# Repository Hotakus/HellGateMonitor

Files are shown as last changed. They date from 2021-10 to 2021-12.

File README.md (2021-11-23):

# Hell Gate Monitor（HGM）
### 微型的MC风格多功能无线监控副屏（开发中）  

### [项目当前待实现目标](https://github.com/Hotakus/HellGateMonitor/issues/3)

---








<div align=center>
    
</div>

---

## 一、基本信息：

> 主控: &emsp; &emsp; ESP32-PICO-D4 (240Mhz，4MB Flash，512KB RAM )  
> PSRAM: &emsp;ESP-PSRAM64 (8MB SPI RAM)   
> 电源管理:&emsp;IP5109  
> IMU: &emsp; &emsp; &nbsp;MPU6050  
> USB串口:&emsp;CP2104    
> LDO芯片:&emsp;XC6210B332 700mA   
> 屏幕: &emsp; &emsp; 1.14英寸 135x240分辨率IPS  
> 锂电池:&emsp; &nbsp; 700mAh 3.7V  
>   
从硬件上看，ESP32系列只要支持**PSRAM**，则代码通用。 

## 二、GUI
[**LittleVGL**](https://github.com/lvgl/lvgl)

---
## 三、基本功能：
>通过蓝牙安卓APP进行Hell Gate Monitor 的 __实时控制与WiFi配置等__  
>通过WiFi对局域网PC进行实时的 __硬件信息监控__ 显示（通过我的另外一个项目 
> [HGMC](https://github.com/Hotakus/HGMC) 后续考虑Linux版本
> ）  
>通过WiFi进行PC的 __屏幕投屏__  
>通过WiFi进行实时的 __天气与时钟显示__  
>通过WiFi进行实时的 __B站基本信息显示__（通过我的蓝牙APP进行B站配置）  

__蓝牙默认名：__ HellGateMonitorBT  
Bluetooth 和 Wi-Fi TCP 与上位机通信的数据包格式为本人规定的固定格式的json数据包组成，采用命令代码方式进行数据交互
，可通过命令和固件定制，添加更多功能。  

[HGM 的蓝牙JSON数据包格式](./Source/HgmApp/HgmBT/README.md)  
[HGM 的WiFi TCP JSON数据包格式](./Source/HgmApp/HgmWiFi/HgmTCP/README.md)

---

## 四、项目克隆：
项目使用了 __子模块__，clone 时要加 __--recurse-submodules__  
需要为你的Github账号配置 SSH key（方法请百度）
```shell
git clone --recurse-submodules git@github.com:Hotakus/HellGateMonitor.git
```

---

## 五、项目基本结构（TDDO）：

---

## 六、开始项目编译（TDDO）
__最后：__  
tb

如果编译烧写正常，那么串口会出现以下信息(115200)：  
HGM  
则项目构建完成。

---

## 七、不会编译，想直接使用👇
如果你觉得编译太麻烦，或者不会编译，
那么可以直接使用我编译好的固件：[固件下载 TODO]()  
然后按照以下流程配置并烧写固件：
- 首先，进入目录：Tool/hgm_spiffs/base_dir/, 按照里面的文件模板进行配置，如WiFi的SSID和密码、B站配置等
- 第二，双击运行目录下的bat脚本：Tool/hgm_spiffs/hgm_spiffs_gen.bat，它会自动生成适用于HGM的spiffs固件
- 第三，USB连接HellGateMonitor，文件和烧写地址要填对，选择正确的串口，
使用Tool下的flash_download_tool工具按如下方式烧写👇。
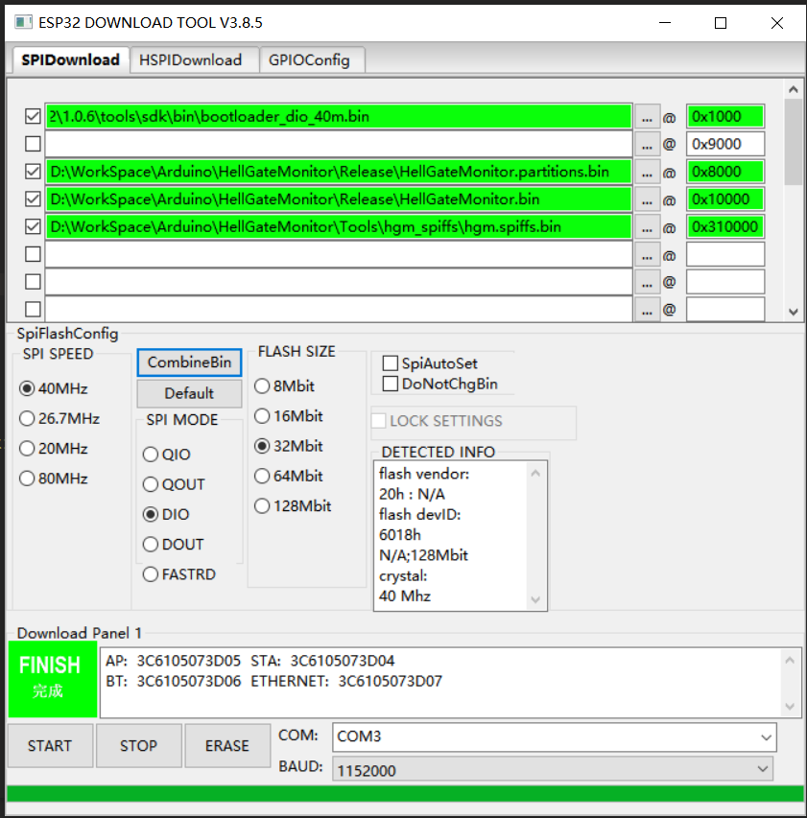
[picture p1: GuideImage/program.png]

- 最后，按下HellGateMonitor的电源键复位，然后就可以开始使用咯✌

---

## 八、HGM的初次上电启动流程（重要）：
HGM的上电时需要对各个功能组件进行检查：  
关于配置文件：如果你使用Tool/hgm_spiffs/hgm_spiffs_gen.bat工具生成的话，运行就不会failed

- **Bluetooth**（用于HGM的控制和配置等）
- **Config**（初次启动没有任何配置文件，首次运行会failed，用 [HGMA](https://github.com/Hotakus/HGMA) 配置）
- **WiFi**（HGM的各个功能基本依赖于此，非常重要，必须进行配置）
- **Time**（基本时钟矫正，开启后每24小时矫正一次）
- **Weather**（天气组件，首次运行会failed，用 [HGMA](https://github.com/Hotakus/HGMA) 配置，每30分钟获取一次）
- **BiliBili**（B站组件，首次运行会failed，用 [HGMA](https://github.com/Hotakus/HGMA) 配置，每10分钟获取一次B站信息）

---

## 九、部分功能上手配置说明：
### 1、如何配置并使用局域网PC硬件监控功能（HGM核心功能）
需要使用我的PC上位机配套项目： [HGMC](https://github.com/Hotakus/HGMC)    
要想使用PC硬件监控功能，那么必须要配合上位机实现，
参考我的另外一个开源项目 [HGMC](https://github.com/Hotakus/HGMC) （PC端硬件监控和HGM投屏管理中心软件），
使用 [HGMC](https://github.com/Hotakus/HGMC) 对PC进行监控或投屏，监控数据会实时发送给HGM，投屏功能可选择开启。

### 2、如何配置并使用天气功能
天气功能所使用的API为“ [和风天气](https://id.qweather.com) ”提供的API
，要想使用天气功能，
那么你必须去“ [和风天气控制台](https://id.qweather.com/#/login?redirect=https%3A%2F%2Fconsole.qweather.com) ”创建应用，
然后获得APP key（免费），这个key是天气功能开启的关键，HGM默认不开启天气功能，要想使用天气功能，
需要获得key后，用 [HGMA](https://github.com/Hotakus/HGMA) （HGM的安卓配置APP）配置HGM，即可使用。

### 3、如何使用安卓APP配置和控制HGM
需要使用我的安卓APP配套项目：[HGMA](https://github.com/Hotakus/HGMA)   

**HGMA**可以干什么？
* 配置WiFi（配置后自动在SPIFFS里生成 **/wifi.conf** 文件，SSID 和 password）
* 配置天气API（配置后自动在SPIFFS里生成 **/weather.conf** 文件，包括APP key和天气获取的默认地区等信息）
* 配置B站信息（配置后自动在SPIFFS里生成 **/bilibili.conf** 文件，即你的B站UID、头像地址等信息）
* 配置 ”硬件监控UI“ 的布局
* 提供简单的蓝牙调试功能，不是HGM也能用

配置完成后，以后每次启动HGM都会优先读取SPIFFS的各个配置文件，以后不用再打开HGMA，除非需要二次配置。

---

## FA♂Q
#### Q: 成本是多少？
A：TODO

---

**开头** 的这些Badge可以点击哦👇👇👇    
prompt

---

<br>
<br>
<br>
<br>
<br>
<br>
<br>
<br>
<br>
<br>
<br>
<br>
<br>

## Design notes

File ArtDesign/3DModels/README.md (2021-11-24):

# HGM 外壳制造
## 一、按照下面流程制造👇
### 3D打印：
精度越高越好，最好给厂家定制  
打印以下3个文件：
* HGM顶盖
* HGM壳
* HGM屏垫片

打印材料：
- PA12-HP工业尼龙（固有色：灰黑色，自己上色）
- PAC-HP尼龙（彩色，贵，彩色文件未上传）

### 亚克力透明底壳（标注2mm厚）：
发给亚克力定制厂家：[HGM透明底壳草图文件.dwg ]()

### 亚克力屏盖（标注0.3mm厚，25mm宽，38mm长）
因为是只有长和宽的需求，所以没有文件，直接和厂家说要这个尺寸

## 二、装配
装配需要另购4个M2自攻螺丝  
TODO

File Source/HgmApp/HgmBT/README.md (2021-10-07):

# HgmBT

HGM的蓝牙数据包格式(JSON)

---

## 下位机数据包格式

|------|数据头标识|数据类型 |数据块 |
|:----:|:---:|:---:|:---:|
| **Key**|Header |DataType  |Data |
| **Value**|HgmBT  |dt (见下文)|data(见下文)|

可以自己添加命令实现更多功能(详见 [BT代码](./HgmBT.h) )



## 数据包示例：
**获取命令长度M（被动）** （DataType == 0）
```json
{
  "Header": "Hgm",
  "DataType": "0",
  "Data": ""
}
```
返回长度M

**普通数据接收（被动）** （DataType == 3）
```json
{
  "Header": "Hgm",
  "DataType": "3",
  "Data": "Hello world! HellGateMonitor!!!"
}
```

普通数据模式下，HGM接收后在串口终端输出相应Data信息

**WiFi配置和开启（被动）** （DataType == 4）

```json
{
  "Header": "Hgm",
  "DataType": "4",
  "Data": {
    "ssid": "xxx",
    "password": "xxx"
  }
}
```

**WiFi关闭（被动）** （DataType == 5）

```json
{
  "Header": "Hgm",
  "DataType": "5",
  "Data": "Any content"
}
```

**天气等信息配置（被动）** （DataType == 6）  
API详见“ [和风天气API](https://dev.qweather.com/docs/api/) ”，若只是使用则不需要了解

```json
{
  "Header": "Hgm",
  "DataType": "6",
  "Data": {
    "lat": "39.92149",
    "lon": "116.48641",
    "key": "xxxxxxxxxxxxxxx"
  }
}
```

**B站配置（被动）** （DataType == 7）

```json
{
  "Header": "Hgm",
  "DataType": "7",
  "Data": {
    "uid": "xxx"
  }
}
```
**配置硬件监控UI（被动）** （DataType == 8）
```json
{
  "Header": "Hgm",
  "DataType": "8",
  "Data": {
    "isDefault" : "1",
    "leftTop" : "CPU",
    "leftBottom" : "GPU",
    "rightTop" : "Memory",
    "rightBottom" : "HardDisk"
  }
}
```
**default** 为 1 代表使用默认配置，为 0 代表使用新配置，并覆写配置文件  
**Data** 候选有：CPU、GPU、Memory、HardDisk、Network

<br>

#### 中间可以添加更多命令........

<br>

**空数据包** （DataType == M）

```json
{
  "Header": "Hgm",
  "DataType": "M",
  "Data": ""
}
```

---

## 上位机接收格式

同 “下位机接收格式”

---

下位机接收成功返回给对方一个JSON数据包：  
OK（DataType == 1）

```json
{
  "Header": "Hgm",
  "DataType": "1",
  "Data": "ok"
}
```

ERROR（DataType == 2）

```json
{
  "Header": "Hgm",
  "DataType": "2",
  "Data": "error"
}
```

---

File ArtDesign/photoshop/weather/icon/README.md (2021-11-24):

#### 天气图标改自：[和风天气天气图标](https://dev.qweather.com/docs/resource/icons/)

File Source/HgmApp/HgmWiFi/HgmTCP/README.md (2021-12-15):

# HgmTCP

HGM的TCP数据包格式(JSON)

---  

蓝牙默认开启，在HGMC与HGM进行TCP连接时，HGMC可手动控制蓝牙开关，
若开启投屏模式，则自动断开蓝牙连接，TCP断开连接或关闭投屏则自动开启蓝牙。
这么做的目的是 为了投屏腾出充足的内存空间，内存中接收的图像数据通过LVGL的机制，
异步刷新显示在屏幕上。  

若HGM在连接状态且打开硬件监控，HGM默认每2秒向HGMC请求一次硬件数据（不建议小于两秒），连续请求失败次数过多则退出监控模式  

## 下位机数据包格式

|------|数据头标识|数据类型 |数据块 |
|:----:|:---:|:---:|:---:|
| **Key**|Header |DataType  |Data |
| **Value**|HgmBT  |dt (见下文)|data(见下文)|

## 数据包示例
**识别当前接入设备是否为HGM（主动）** （DataType == 0）
```json
{
  "Header": "HgmTCP",
  "DataType": "0",
  "Data": "HellGateMonitor"
}
```
匹配后，匹配标志置为真

**从HGMC请求硬件参数（主动）** （DataType == 3）
```json
{
  "Header": "HgmTCP",
  "DataType": "3",
  "Data": {
    "CPU" : "1",
    "GPU" : "1",
    "Memory" : "1",
    "HardDisk" : "1",
    "Network" : "0"
  }
}
```

**数据源匹配（被动）** （DataType == 5）
```json
{
  "Header": "HgmTCP",
  "DataType": "5",
  "Data": "match"
}
```

1 为请求，0 为不请求  
请求成功则接收到OK数据包，紧跟着“硬件信息”数据包

**硬件信息数据包** （DataType == 4）  
[硬件信息数据包JSON示例文件](HardwareJsonPack.json)  
若发送请求时未请求对应的硬件信息，则对应参数返回空值，若对应参数请求但返回空值，则认为其请求错误（待实现）

**TCP普通数据模式（被动）** （DataType == M-1）
```json
{
  "Header": "HgmTCP",
  "DataType": "M-1",
  "Data": "Hello HellGateMonitor"
}
```
普通数据模式下，显示Data内容到HGM串口

**投屏开启** （DataType == 6）

```json
{
  "Header": "HgmTCP",
  "DataType": "6",
  "Data": {
    "cf": "JPG"  // 表明本次投屏图像格式，如JPG、PNG、RAW
  }
}
```
在投屏模式下，并收到投屏图像帧信息数据包时，则开启投屏一帧图像，每接收到一帧则投一帧，
无接收则停止。  
一帧投屏数据由三部分组成：
- 帧头（0x20 0x21 0x12，共三字节）
- 主体图像数据
  - 图像帧长度（三字节，例：0x10，0x20，0x30）
    - 则字节数：(0x10<<16) | (0x20<<8) | (0x30<<0) = 1056816 Bytes = 1032 KiB
  - 指定格式图像数据（JPG、PNG、RAW的原始数据）
- 帧尾（0x12 0x21 0x20，共三字节）
---

**投屏结束** （DataType == 7）

```json
{
  "Header": "HgmTCP",
  "DataType": "7",
  "Data": ""
  }
```

下位机接收成功返回给对方一个JSON数据包：  
OK（DataType == 1）

```json
{
  "Header": "HgmTCP",
  "DataType": "1",
  "Data": "ok"
}
```

ERROR（DataType == 2）

```json
{
  "Header": "HgmTCP",
  "DataType": "2",
  "Data": "error"
}
```

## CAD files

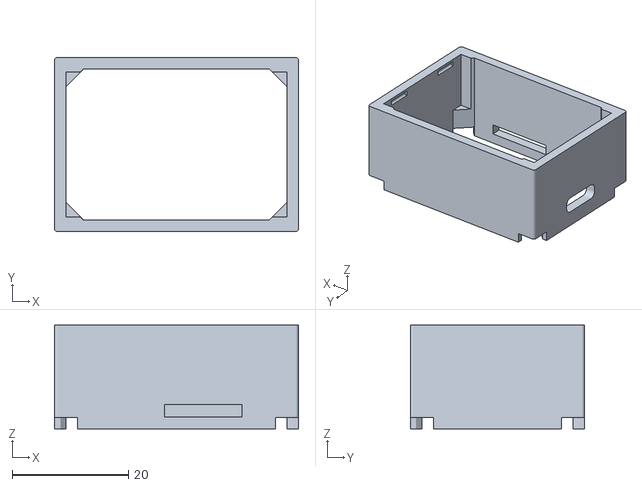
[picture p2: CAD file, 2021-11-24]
ArtDesign/3DModels/HGM壳.stl
42.0 x 30.0 x 17.9

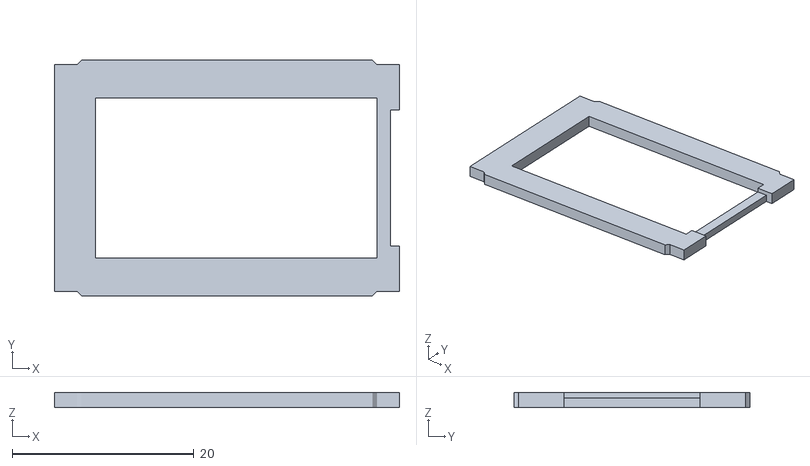
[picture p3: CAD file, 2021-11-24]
ArtDesign/3DModels/HGM屏垫片.stl
38.0 x 26.0 x 1.60

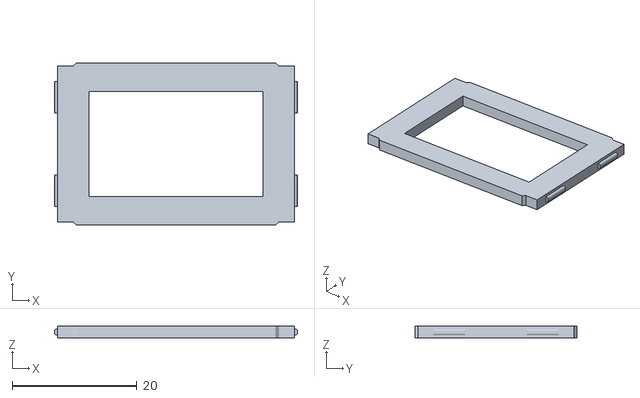
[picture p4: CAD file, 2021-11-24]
ArtDesign/3DModels/HGM顶盖.stl
39.0 x 26.0 x 2.00

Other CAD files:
ArtDesign/3DModels/HGM透明底壳草图文件.dwg

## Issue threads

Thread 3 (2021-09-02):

TODO list

Hotakus, 2021-09-02:
- [x] Optimize the background's file size (use imgbtn)
- [ ] perf the weather's analysis
- [ ] perf the lvgl ui (designing)
- [ ] feat the hardware info get
- [ ] feat the screen projection
- [x] perf the BT module
- [ ] perf the time info class API
- [x] fix the bug that BT and WiFi can't run meantime(add a semaphore)
- [ ] feat new BT command: close BT

Hotakus, 2021-09-25:
欲添加LVGL硬件监控对象，包含硬件数据对象和UI对象：
- UI对象控制UI行为，例如UI的进场与退场，及前台数据更新等；
- 硬件数据对象存放UI位置信息、硬件类型与其监控数据

LVGL硬件监控对象固定为4，UI位置分别为左上、左下、右上、右下，通过绑定不同的UI对象与不同的硬件数据对象，实现硬件监控UI的更替与数据的更替

- [ ] 创建 “LVGL硬件监控对象”
- [ ] 创建 “UI对象”
- [ ] 创建 “硬件数据对象”

Hotakus, 2021-09-26:
## 重写WiFi和蓝牙的实现框架

- [ ] 完成

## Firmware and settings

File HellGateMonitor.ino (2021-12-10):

/******************************************************************
 * @file HellGateMonitor.ino
 * @author Hotakus (...)
 * @email ttowfive@gmail.com
 * @brief ...
 * @version 1.0
 * @date 2021/8/11 20:19
 * @copyright Copyright (c) 2021/9/16
*******************************************************************/

/* User include files */
#include "Source/HgmApp/HgmWiFi/HgmWiFi.h"
#include "Source/HgmApp/HgmBT/HgmBT.h"
#include "Source/HgmLvgl/HgmLvgl.h"
#include "Source/HgmSelfChecking/HgmSelfChecking.h"
#include "Source/HgmApp/TimeInfo/TimeInfo.h"
#include "Source/HgmApp/BiliInfoRecv/BiliInfoRecv.h"
#include "Source/HgmLvgl/HgmGUI/HgmSetupView.h"
#include "Source/HgmApp/WeatherInfo/WeatherInfo.h"
#include "Source/HgmApp/HotakusMemUtil.h"
#include "Source/HgmApp/HotakusHttpUtil.h"
#include "Source/HgmApp/HardwareInfoRecv/HardwareRequest.h"
#include "Source/Utils/MsgCenter/MsgCenter.h"
#include "Source/Utils/SPIFFSUtil/SPIFFSUtil.h"

#include <TFT_eSPI.h>
#include <User_Setup.h>
#include <User_Setup_Select.h>
#include <I2C_MPU6886.h>
#include <ArduinoJson.h>
#include <iostream>
#include <TJpg_Decoder.h>
#include <SPIFFS.h>
#include <freertos/FreeRTOSConfig.h>

#define SCREEN_BK_PIN   32

#define HGM_VERSION_INFO  "dev"
#define HGM_VERSION_MAJOR 0
#define HGM_VERSION_MINOR 8
#define HGM_VERSION_PATCH 6

#define COMPILE_DATE __DATE__
#define COMPILE_TIME __TIME__

using namespace HGM;
using namespace HgmGUI;
using namespace HgmApplication;
using namespace fs;
using namespace msgmanager;
using namespace spiffsutil;

extern HgmWiFi hgmWiFi;
extern HgmBT hgmBT;
extern TimeInfo ti;
extern BiliInfoRecv bili;
extern WeatherInfo weatherInfo;
extern HgmLvgl hgmLvgl;

static QueueHandle_t bkMsgBox;
static TaskHandle_t bkHandle;

SemaphoreHandle_t wbs;

float firmwareSize = 0;

// Show the init progress task
static void backlightControl(void* params)
{
    bool flag = false;
    
    ledcAttachPin(SCREEN_BK_PIN, 0);
    ledcSetup(0, (10 * 1000), 8);   // PWM 10kHz
    ledcWrite(0, 0);

    while (true) {
        if (xQueueReceive(bkMsgBox, &flag, portMAX_DELAY) != pdPASS)
            continue;
        if (flag) {
            for (size_t i = 0; i < 127; i++) {
                ledcWrite(0, i);
                vTaskDelay(13);
            }
        } else {
            for (size_t i = 127; i > 0; i--) {
                ledcWrite(0, i);
                vTaskDelay(13);
            }
        }
    }
}

void setup()
{
    Serial.begin(115200);

    firmwareSize = ESP.getSketchSize() / 1024.0 / 1024.0;

    Serial.printf("\n****************** Hell Gate Monitor ******************\n");
    Serial.printf("           ___           ___           ___               \n");
    Serial.printf("          /\\__\\         /\\  \\         /\\__\\        \n");
    Serial.printf("         /:/  /        /::\\  \\       /::|  |           \n");
    Serial.printf("        /:/__/        /:/\\:\\  \\     /:|:|  |          \n");
    Serial.printf("       /::\\  \\ ___   /:/  \\:\\  \\   /:/|:|__|__      \n");
    Serial.printf("      /:/\\:\\  /\\__\\ /:/__/_\\:\\__\\ /:/ |::::\\__\\ \n");
    Serial.printf("      \\/__\\:\\/:/  / \\:\\  /\\ \\/__/ \\/__/~~/:/  /  \n");
    Serial.printf("           \\::/  /   \\:\\ \\:\\__\\         /:/  /     \n");
    Serial.printf("           /:/  /     \\:\\/:/  /        /:/  /          \n");
    Serial.printf("          /:/  /       \\::/  /        /:/  /            \n");
    Serial.printf("          \\/__/         \\/__/         \\/__/           \n\n");
    Serial.printf("Date     : %s %s\n", COMPILE_DATE, COMPILE_TIME);
    Serial.printf("ESP-IDF  : %s\n", ESP.getSdkVersion());
    Serial.printf("FreeRTOS : %s\n", tskKERNEL_VERSION_NUMBER);
    Serial.printf("LVGL     : V%d.%d.%d %s\n", lv_version_major(), lv_version_minor(), lv_version_patch(),
        lv_version_info());
    Serial.printf("Firmware : V%d.%d.%d %s %0.2f MiB\n", HGM_VERSION_MAJOR, HGM_VERSION_MINOR, HGM_VERSION_PATCH,
        HGM_VERSION_INFO, firmwareSize);
    Serial.printf("Github   : https://github.com/Hotakus/HellGateMonitor \n");
    Serial.printf("********************************************************\n");

    bkMsgBox = xQueueCreate(1, sizeof(bool));
    xTaskCreatePinnedToCore(backlightControl, "backlightControl", 1024 + 128, NULL, 5, &bkHandle, 1);

    // Semaphore for BT and WiFi. Don't remove it
    wbs = xSemaphoreCreateBinary();
    xSemaphoreGive(wbs);
    
    /* HGM LVGL initialize */
    hgmLvgl.begin();

    bool flag = true;
    xQueueSend(bkMsgBox, &flag, portMAX_DELAY); // Open backlight

    HgmSC* hgmSC = new HgmSC;
    hgmSC->begin();
    delete hgmSC;

    hgmLvgl.guiBegin();
    
    char* task_buf = (char*)hotakusAlloc(8192); 
    vTaskList(task_buf);
    Serial.printf("%s\n", task_buf);
    hotakusFree(task_buf);

    // vTaskDelay(5000);
    // hgmLvgl.hgmFw->changeGUI("HgmTw");
    // vTaskDelay(15000);
    // hgmLvgl.hgmFw->changeGUI("HgmMonitor");
    // vTaskDelay(15000);
    // hgmLvgl.hgmFw->changeGUI("HgmTw");
    // vTaskDelay(15000);
    // hgmLvgl.hgmFw->changeGUI("HgmMonitor");
    // vTaskDelay(15000);
    // hgmLvgl.hgmFw->changeGUI("HgmTw");
    // vTaskDelay(15000);
    // hgmLvgl.hgmFw->changeGUI("HgmMonitor");
    // vTaskDelay(15000);
    // hgmLvgl.hgmFw->changeGUI("HgmTw");
    // vTaskDelay(15000);
    // hgmLvgl.hgmFw->changeGUI("HgmMonitor");
    // vTaskDelay(15000);

}

static size_t t = 0;
void loop()
{
    Serial.printf("[%ds][%d] free mem : %d\n", t, uxTaskGetNumberOfTasks(),
        heap_caps_get_free_size(MALLOC_CAP_INTERNAL));

    // vTaskDelay(10 * 60 * 1000);
    t += 2;
    vTaskDelay(2000);
}

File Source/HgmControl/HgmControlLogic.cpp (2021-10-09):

/******************************************************************
 * @file HgmControlLogic.cpp
 * @author Hotakus (ttowfive@gmail.com)
 * @brief ...
 * @version 1.0
 * @date 2021-08-09
 * @copyright Copyright (c) 2021
 *******************************************************************/

#include <Arduino.h>
#include <I2C_MPU6886.h>
#include "HgmControlLogic.h"

using namespace HGM;

HgmControlLogic::HgmControlLogic(TwoWire& i2cPort)
{
    this->imu = new I2C_MPU6886(I2C_MPU6886_DEFAULT_ADDRESS, i2cPort);
    this->RelativeGyroValueConfig(&_gx, &_gy, &_gz);
    this->RelativeAccelValueConfig(&_ax, &_ay, &_az);

    this->i2cSemaphore = xSemaphoreCreateBinary();
    xSemaphoreGive(this->i2cSemaphore);
}

HgmControlLogic::~HgmControlLogic()
{
    delete this->imu;
}

void HgmControlLogic::HgmControlbegin()
{
    this->imu->begin();
}

void HgmControlLogic::GetAccelRowParams()
{
    this->imu->getAccel(&_ax, &_ay, &_az);
}

void HgmControlLogic::GetGyroRowParams()
{
    this->imu->getGyro(&_gx, &_gy, &_gz);
}

void HGM::HgmControlLogic::RelativeGyroValueConfig(float* dgx, float* dgy, float* dgz)
{
    this->dgx = dgx;
    this->dgy = dgy;
    this->dgz = dgz;
}

void HGM::HgmControlLogic::RelativeAccelValueConfig(float* dax, float* day, float* daz)
{
    this->dax = dax;
    this->day = day;
    this->daz = daz;
}

/**
 * @brief Analyze task..
 * @return MotionType
 */
MotionType HGM::HgmControlLogic::AnalyzeTask()
{
    xSemaphoreTake(this->i2cSemaphore, portMAX_DELAY);
    this->GetAccelRowParams();
    this->GetGyroRowParams();
    xSemaphoreGive(this->i2cSemaphore);

    this->AnalyzeMotion();

    if (this->mt == MotionType::NULL_MOTION)
        return MotionType::NULL_MOTION;

    switch (this->mt) {
    case MotionType::CLOCKWISE:
        Serial.println("Clockwise");
        break;
    case MotionType::ANTICLOCKWISE:
        Serial.println("Anticlockwise");
        break;
    case MotionType::RIGHT_TO_LEFT:
        Serial.println("RTL");
        break;
    case MotionType::LEFT_TO_RIGHT:
        Serial.println("LTR");
        break;
    case MotionType::RISE_HEAD:
        Serial.println("Rise head");
        break;
    case MotionType::DOWN_HEAD:
        Serial.println("Down head");
        break;
    default:
        break;
    }

    return this->mt;
}

float HGM::HgmControlLogic::GetTemperature()
{
    xSemaphoreTake(this->i2cSemaphore, portMAX_DELAY);
    static float last_temp = this->temp;
    this->imu->getTemp(&this->temp);
    if (this->temp > 100)
        this->temp = last_temp;
    xSemaphoreGive(this->i2cSemaphore);

    return temp;
}

/**
 * @brief  Analyze the Motion of the imu.
 */
void HGM::HgmControlLogic::AnalyzeMotion()
{
    /*Serial.printf("GX: %0.2f\n", *dgx);
    Serial.printf("GY: %0.2f\n", *dgy);
    Serial.printf("GZ: %0.2f\n", *dgz);*/

    this->mt = MotionType::NULL_MOTION;

    if (*dgz >= GZ_THRESHOLD)
        mt = MotionType::ANTICLOCKWISE;
    else if (*dgz <= -GZ_THRESHOLD)
        mt = MotionType::CLOCKWISE;
    else if (*dgy >= GY_THRESHOLD)
        mt = MotionType::LEFT_TO_RIGHT;
    else if (*dgy <= -GY_THRESHOLD)
        mt = MotionType::RIGHT_TO_LEFT;
    else if (*dgx >= GX_THRESHOLD)
        mt = MotionType::DOWN_HEAD;
    else if (*dgx <= -GX_THRESHOLD)
        mt = MotionType::RISE_HEAD;
}

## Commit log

2021-08-09 Complete the framework of the HGM Control Logic
2021-08-10 Complete the framework of the lvgl
2021-08-11 Optimize the framework of GUI
2021-08-12 Complete the framework of the WiFi
2021-08-12 Finish the framework of the TCP
2021-08-13 Finish the basic bluetooth framework
2021-08-13 Optimize some framework
2021-08-14 Finish " the framework that function of the wifi config via bluetooth."
2021-08-16 Basic framework test ok
2021-08-19 perf(setup UI) Optimize the basic framework
2021-08-19 fix(setup UI) bug of the parameters
    [HgmTCP.cpp]
2021-08-20 fix(wifi) some bugs in boot progress
    [HellGateMonitor.ino, HgmBT.cpp, HgmSelfChecking.cpp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]
2021-08-20 feat(net time) complete the framework
2021-08-22 perf(BT) optimize the basic framework
2021-08-31 feat(tw ui): add the basic framework
2021-09-01 fix(HgmBT) fix some bugs
    [HgmBT.cpp]
2021-09-02 perf(WeatherInfo) perfect the framework
2021-09-02 fix(BT WiFi) add mutex for them
    [HellGateMonitor.ino, HgmBT.cpp, HgmTCP.cpp]
2021-09-02 docs(TODO) move TODO list to issue page
    [HellGateMonitor.ino]
2021-09-04 fix(WiFi) fix some bugs and optimize code
    [HellGateMonitor.ino, HgmBT.cpp, HgmSelfChecking.cpp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]
2021-09-04 perf(bilibili) completed the framework of the bilibili info get
2021-09-04 fix(mutex logic) some bugs
    [BiliInfoRecv.cpp, HellGateMonitor.ino, HgmSelfChecking.cpp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]
2021-09-14 fix(BT) command analysis error
    [HgmBT.cpp]
2021-09-21 fix(setup ui) unsafe task operation
    [HellGateMonitor.ino, HgmTCP.cpp]
2021-09-21 feat(hardware data) create basic framework
2021-09-22 fix(Hardware data) GPU and memory
    [HgmTCP.cpp]
2021-09-24 feat(hardware) create hardware object framework
2021-09-26 fix(weather) get error when bluetooth is opening
    [BiliInfoRecv.cpp, HellGateMonitor.ino, HgmTCP.cpp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]
2021-10-02 fix(priority) elevate LVGL's priority
    [HellGateMonitor.ino, HgmTCP.cpp, TimeInfo.cpp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]
2021-10-03 fix: elevate the stability of WiFi and BT
    [BiliInfoRecv.cpp, HellGateMonitor.ino, HgmBT.cpp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]
2021-10-04 perf(port) using spi ram
2021-10-04 perf(JSON) use spi ram
2021-10-06 fix(bili) create refresh timer
2021-10-07 fix(HgmApp) http timeout bug
    [BiliInfoRecv.cpp, TimeInfo.cpp]
2021-10-07 fix(BiliInfoRecv) bug that maybe getting data is error
    [BiliInfoRecv.cpp]
2021-10-07 feat(hgm_tools) add spiffs tool
    [partitions.csv]
2021-10-08 fix some mem bugs
    [BiliInfoRecv.cpp, HellGateMonitor.ino, HgmBT.cpp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]
2021-10-08 fix(bili) wait it get done
    [BiliInfoRecv.cpp]
2021-10-08 fix(weather) get raw data error from qweather
    [HellGateMonitor.ino, HgmWiFi.cpp, WeatherInfo.cpp]
2021-10-14 fix(bili) maybe error when GET
    [BiliInfoRecv.cpp, HellGateMonitor.ino, WeatherInfo.cpp]
2021-10-14 fix(wifi) maybe error when task return
    [HgmWiFi.cpp]
2021-10-23 perf(hardware request) optimize request framework
2021-10-24 feat(hardware) accomplish hardware framework
2021-10-26 feat(GUI Framework) new framework
2021-10-27 perf framework
2021-10-27 feat(MsgCenter) Msg framework
2021-10-29 refactor GUI framework
2021-10-30 Revert "perf(bili) uid get and set"
    This reverts commit 409ce9074a9bd81522d4ed6697b4db04f9e69ca3.
    [BiliInfoRecv.cpp]
2021-10-30 Revert "perf(bili) uid get and set"
    This reverts commit 91d3cf3d3ea8d00e9c924f20c04cf029ae44acf2.
    [HgmBT.cpp]
2021-11-10 fix(hgm framewrok) logic error
2021-11-13 perf(monitor) monitor frame's pos according to hrr preset
2021-11-13 perf(monitor view) framework
2021-11-24 fix(lv mem) memory leakage
    [HgmTwView.cpp]
2021-11-24 update models' designs
    [HGM壳.stl, HGM屏垫片.stl, HGM透明底壳草图文件.dwg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]
2021-11-25 fix hazardous usage may cause crush
    [BiliInfoRecv.cpp, HellGateMonitor.ino, HgmTwView.cpp]
2021-12-12 test(sr) complete the framework of screen receiver
